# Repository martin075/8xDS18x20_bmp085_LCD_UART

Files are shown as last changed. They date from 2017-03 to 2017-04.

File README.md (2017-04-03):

# 8xDS18x20_bmp085_LCD_UART
it is continue of Tom Blough's termometer. contain Davide Gironi libs BMP085.calculation of pressure must be checked.
project in Atmel Studio 4.18, atmel tool chain 3.4.4, avr-gcc 4.8.1, Fleury's libs uart, twi, i2c updated, Atmega168 8 MHz internal
DS18b20, DS18s20, LCD lib

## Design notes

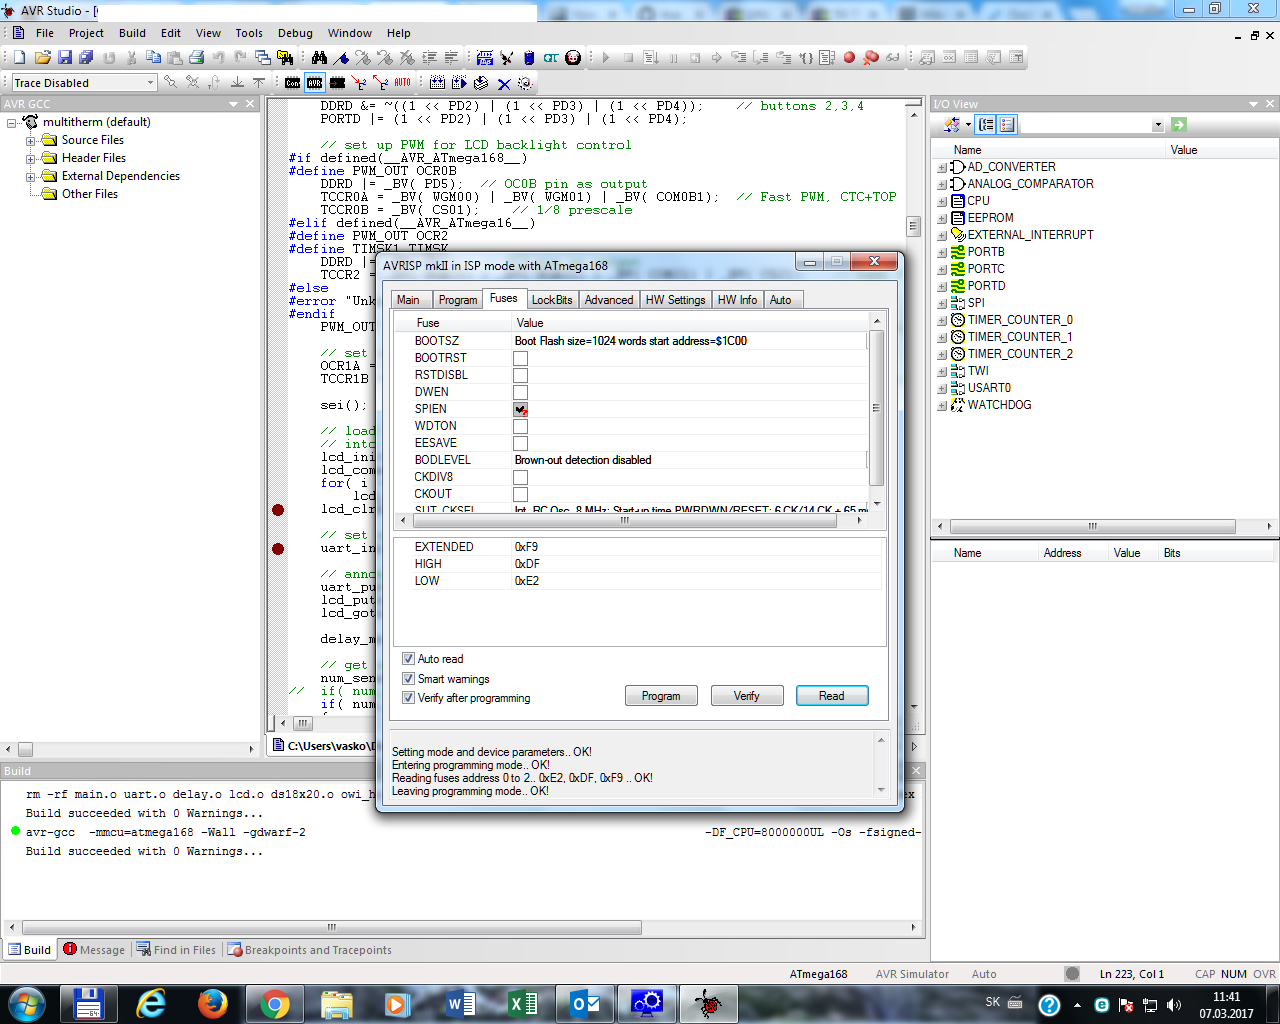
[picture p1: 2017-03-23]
poistky8mhz.png

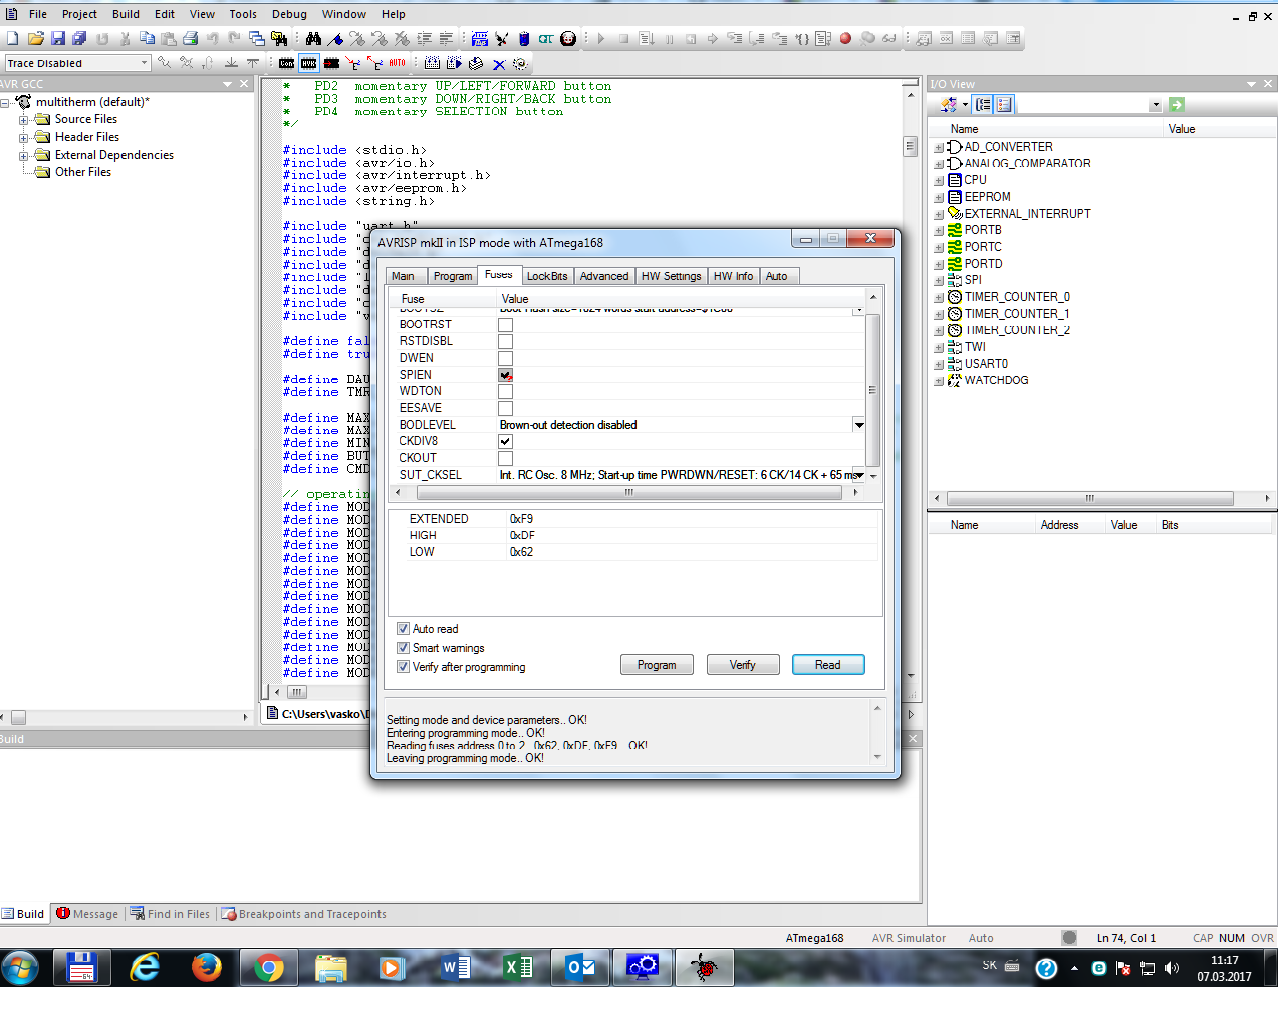
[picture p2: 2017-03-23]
poistky.png

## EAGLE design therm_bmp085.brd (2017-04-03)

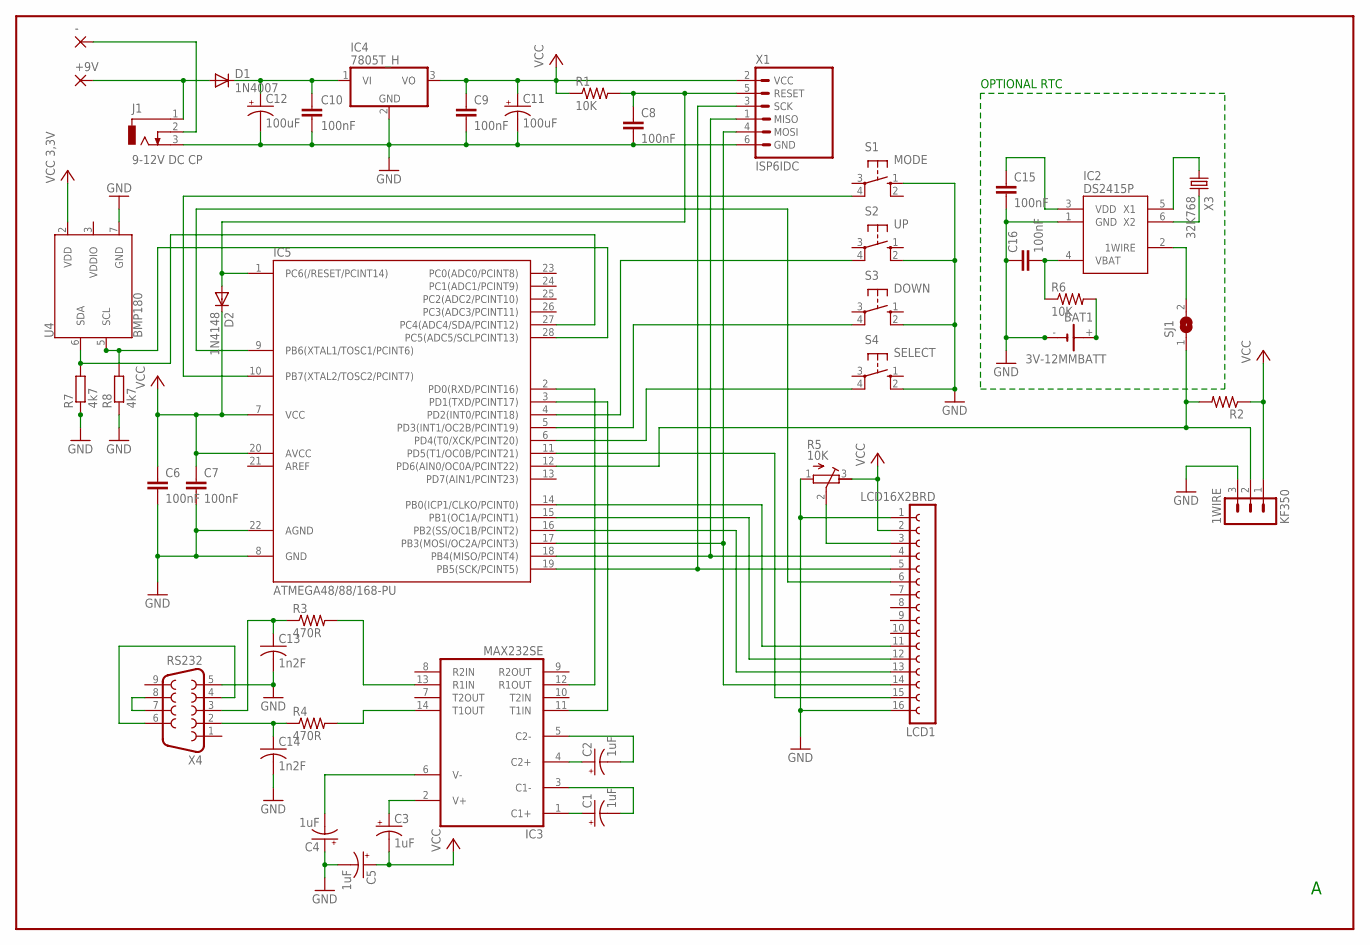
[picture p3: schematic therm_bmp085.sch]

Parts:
1WIRE: KF350
+9V: WIREPAD3,17/1,1; 3,17/1,1
-: WIREPAD3,17/1,1; 3,17/1,1
BAT1: 3V-12MMBATT; KEYELCO3001
C1, C2, C3, C4, C5: 1uF; CT3528
C6, C7, C8, C15, C16: 100nF; C0805
C9, C10: 100nF; C025_050-024X070
C11, C12: 100uF; E2,5-7
C13, C14: 1n2F; C0805
D1: 1N4007; D-10
D2: 1N4148; DO34-7
IC2: DS2415P; TSOC6
IC3: MAX232SE; SO16
IC4: 7805T_H; TO220H
IC5: ATMEGA48/88/168-PU; DIL28-3
J1: 9-12V DC CP; DCJ0202
LCD1: LCD16X2BRD; LCD16X2
R1, R6: 10K; R0805
R2: R-US_0207/10; 0207/10
R3, R4: 470R; R0805
R5: 10K; RTRIM5X
R7, R8: 4k7; 0204V
S1: MODE; B3F-10XX
S2: UP; B3F-10XX
S3: DOWN; B3F-10XX
S4: SELECT; B3F-10XX
SJ1: SJ
U4: BMP180
X1: ISP6IDC; IDC-6
X3: 32K768; TC38H_SMD
X4: RS232; F09D

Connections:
+9V: +9V.1, D1.A, J1.1
GND: 1WIRE.3, BAT1.-, BAT1.-1, BAT1.-2, BAT1.-3, C4.+, C5.-, C6.2, C7.2, C8.2, C9.2, C10.3 (1), C11.-, C12.-, C13.2, C14.2, C15.2, C16.1, IC2.1 (GND), IC3.15 (GND), IC4.2 (GND), IC5.8 (GND), IC5.22 (AGND), J1.3, LCD1.1, LCD1.16, R5.1 (E), R7.1, R8.1, S1.1 (S), S2.2 (S1), S3.2 (S1), S4.2 (S1), U4.7 (GND), X1.6 (GND), X4.5
unnamed: C10.2, C12.+, D1.C, IC4.1 (VI)
unnamed: C3.+, IC3.2 (V+)
unnamed: C4.-, IC3.6 (V-)
unnamed: IC3.12 (R1OUT), IC5.2 (PD0(RXD/PCINT16))
unnamed: IC3.11 (T1IN), IC5.3 (PD1(TXD/PCINT17))
unnamed: C14.1, R4.1, X4.2
unnamed: IC3.14 (T1OUT), R4.2
unnamed: C13.1, R3.1, X4.3
unnamed: IC3.13 (R1IN), R3.2
unnamed: X4.7, X4.8
unnamed: X4.4, X4.6
unnamed: C1.+, IC3.1 (C1+)
unnamed: C1.-, IC3.3 (C1-)
unnamed: C2.-, IC3.5 (C2-)
unnamed: C2.+, IC3.4 (C2+)
unnamed: LCD1.3, R5.2 (S)
unnamed: IC5.10 (PB7(XTAL2/TOSC2/PCINT7)), S1.4 (P1)
unnamed: IC5.9 (PB6(XTAL1/TOSC1/PCINT6)), LCD1.6
unnamed: IC5.19 (PB5(SCK/PCINT5)), LCD1.5, X1.3 (SCK)
unnamed: IC5.18 (PB4(MISO/PCINT4)), LCD1.4, X1.1 (MISO)
unnamed: IC5.17 (PB3(MOSI/OC2A/PCINT3)), LCD1.14, X1.4 (MOSI)
unnamed: IC5.16 (PB2(SS/OC1B/PCINT2)), LCD1.13
unnamed: IC5.15 (PB1(OC1A/PCINT1)), LCD1.12
unnamed: IC5.14 (PB0(ICP1/CLKO/PCINT0)), LCD1.11
unnamed: IC5.11 (PD5(T1/OC0B/PCINT21)), LCD1.15
unnamed: IC5.4 (PD2(INT0/PCINT18)), S2.4 (P1)
unnamed: IC5.5 (PD3(INT1/OC2B/PCINT19)), S3.4 (P1)
unnamed: IC5.6 (PD4(T0/XCK/PCINT20)), S4.4 (P1)
unnamed: 1WIRE.2, IC5.12 (PD6(AIN0/OC0A/PCINT22)), R2.2, SJ1.1
unnamed: IC2.6 (X2), X3.P$2 (2)
unnamed: IC2.5 (X1), X3.P$1 (1)
unnamed: C8.1, D2.A, IC5.1 (PC6(/RESET/PCINT14)), R1.2, X1.5 (RESET)
unnamed: -.1, J1.2
unnamed: IC2.2 (1WIRE), SJ1.2
unnamed: C15.1, IC2.3 (VDD)
unnamed: BAT1.+, BAT1.+1, R6.2
unnamed: IC5.27 (PC4(ADC4/SDA/PCINT12)), IC5.28 (PC5(ADC5/SCLPCINT13)), R7.2, R8.2, U4.5 (SCL), U4.6 (SDA)
VBAT: C16.2, IC2.4 (VBAT), R6.1
VCC: 1WIRE.1, C3.-, C5.+, C6.1, C7.1, C9.3 (1), C11.+, D2.C, IC3.16 (VCC), IC4.3 (VO), IC5.7 (VCC), IC5.20 (AVCC), LCD1.2, R1.1, R2.1, R5.3 (A), U4.2 (VDD), X1.2 (VCC)

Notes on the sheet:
OPTIONAL RTC

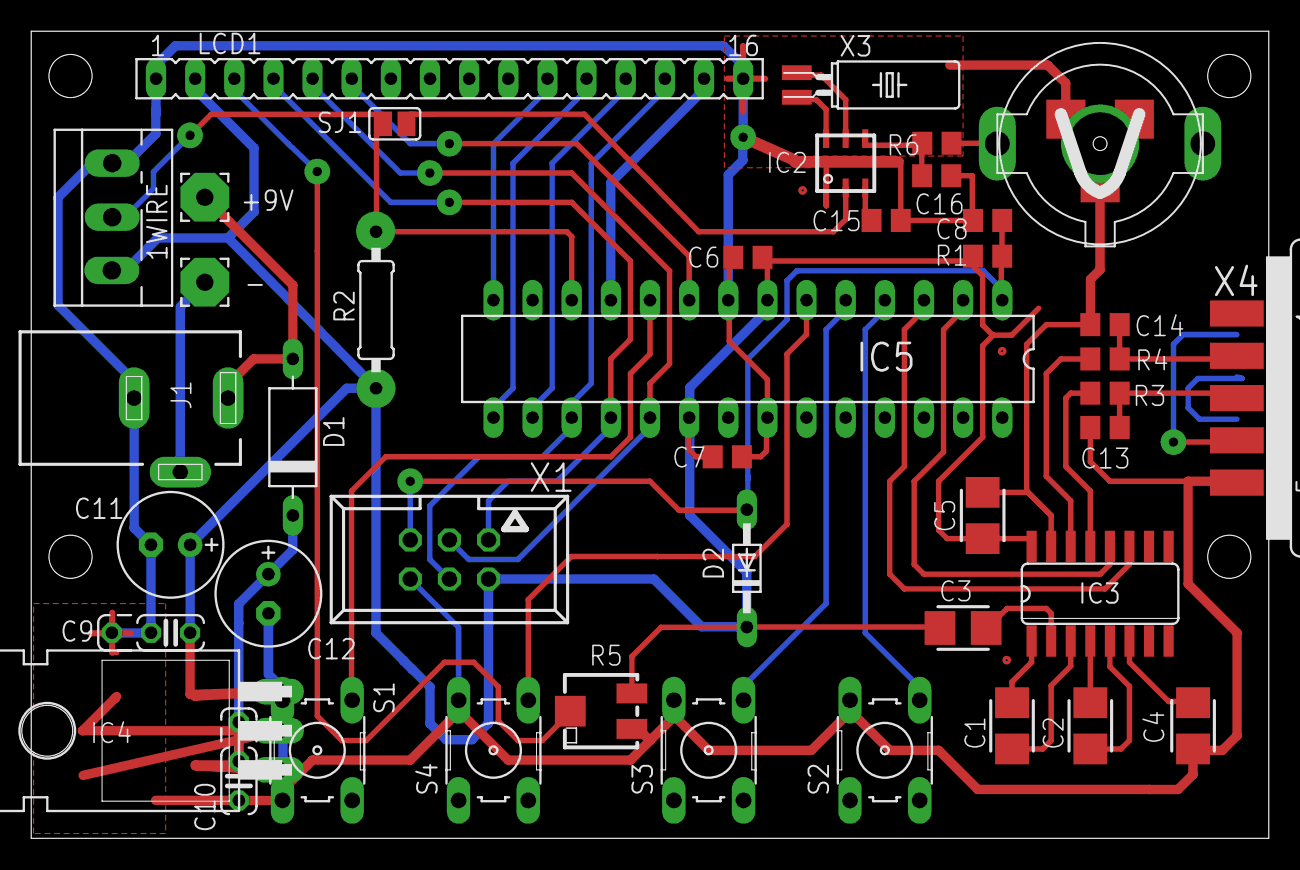
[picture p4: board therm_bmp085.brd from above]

Board: 2 copper layers, 80.3 x 52.4 mm, 42 parts (0 on the bottom side), 40 nets.

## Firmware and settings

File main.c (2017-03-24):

/*
* Program: Multitherm - A multiple DS18x20 thermometer control and logging device
* File Name: crc.c
* Purpose: Implements an AVR based temperature logging device
*
*	Reads multiple Dallas Semiconductor DS18x20 1-Wire
*	thermometers and sends the data via serial port for
*	logging by an external program.  Displays the
*	temperature data via an attached LCD as well.  Serial records
*	are timestamped using an elapsed time counter value, or a DS2415
*	1-Wire Real Time Clock timestamp if the device is present
*	on the 1-Wire bus.
*
*	Uses Peter Fleury's uart-library and lcd-library
*	which are very portable between AVRs.  Martin Thomas
*	added some functions in the uart-lib.
*
*	Contains code from DS18x20 Demo-Programm by
*	Martin Thomas <eversmith@heizung-thomas.de>
*	http://www.siwawi.arubi.uni-kl.de/avr-projects
*
*	Created using Atmel STK500, Atmega16L @ 8MHz
*	internal oscillator clock.
*
*    Programmer: Tom Blough
*   Host System: ATMega16L tested with both internal RC osc at 8MHz
*                and external 8MHz crystal
*  Date Created: 2007/09/20
*      Revision: 2007/12/18 - loop page display and sensor display
*                             fix bug in initial sensor order - was not writing to nvRam
*                2008/08/16 - added sanity checks when loading data from SRAM
*                2017/03     added saving adresses into EEPROM 
*				 2017/03 - upgraded libs UART.c, UART.h for avr-gcc 4.8.1 (Fleury 2015)
*				 2017/03 - reading data from BMP085 - temp, altitude, pressure
*                do not mix 18b20 family and 1820/18s20
*
* Host Configuration ATMega16:
*	PB0  LCD_DATA_4
*	PB1  LCD_DATA_5
*	PB2  LCD_DATA_6
*	PB3  LCD_DATA_7
*	PB4  LCD_DATA_RS
*	PB5  LCD_DATA_R/W
*	PB6  LCD_DATA_E
*
*	PD0  RxD, 19200,8,n,1
*	PD1  TxD
*	PD6  1-Wire Data, external 15K pullup
*	PD7  PWM LCD Backlight (OC2)
*
*	PB7  momentary MODE button
*	PD2  momentary UP/LEFT/FORWARD button
*	PD3  momentary DOWN/RIGHT/BACK button
*	PD4  momentary SELECTION button
*
* Host Configuration ATMega168, 8MHz:
*  note- on STK500, PB6 and PB7 are not routed to PortB header
*  instead they are routed to PortE XT1/XT2
*	PB0  LCD_DATA_4
*	PB1  LCD_DATA_5
*	PB2  LCD_DATA_6
*	PB3  LCD_DATA_7
*	PB4  LCD_DATA_RS
*	PB5  LCD_DATA_R/W
*	PB6  LCD_DATA_E
*
*	PD0  RxD, 19200,8,n,1
*	PD1  TxD
*	PD6  1-Wire Data, external 15K pullup
*	PD5  PWM LCD Backlight (OC2)
*
*	PB7  momentary MODE button
*	PD2  momentary UP/LEFT/FORWARD button
*	PD3  momentary DOWN/RIGHT/BACK button
*	PD4  momentary SELECTION button
*/

#include <stdio.h>
#include <avr/io.h>
#include <avr/interrupt.h>
#include <avr/eeprom.h>
#include <string.h>

#include "uart.h"
#include "owi_highlevel.h"
#include "ds18x20.h"
#include "ds2415.h"
#include "lcd.h"
#include "delay.h"
#include "crc.h"
#include "version.h"

// libs for BMP085
#include "bmp085.h"
#include <math.h>

#define false 0
#define true !false

#define BAUD 19200
#define TMR_TICK 200L	// 200Hz = 5ms

#define MAX_SENSORS 8			// we can handle only sensor ID's from 0-9 (display constraint on order page)
#define MAX_INTERVAL 9999	// maximum number of seconds between log entries
#define MIN_INTERVAL 5		// minimum number of seconds between log entries
#define DEF_INTERVAL 15		//default interval of log entries, sec
#define HYSTER 10					// hysterezia 
#define DEF_BACKLIGHT 240	//default value of backlight
#define BUTTON_HELD 3			// number of CMD_DELAY cycles until button considered held
#define CMD_DELAY 200			// ms to wait between command executions

// operating states
#define MODE_LOGGING 0	// actively reading and logging temperatures
#define MODE_START 1	// displaying start logging message
#define MODE_ORDER 2	// displaying change view order
#define MODE_INTERVAL 3	// displaying interval change
#define MODE_SENSOR 4	// displaying extended sensor info
#define MODE_BACKLIGHT 5	// displaying PWM LCD backlight change
#define MODE_SHOW_DATE 6	// display RTC date
#define MODE_SET_YEAR 7	// change year value
#define MODE_SET_MONTH 8	// change month value
#define MODE_SET_DAY 9	// change day value
#define MODE_SET_HOUR 10	// change hour value
#define MODE_SET_MIN 11	// change minutes value
#define MODE_SET_SEC 12	// change seconds value
#define MODE_WRITE_DATE 13	// commit changes to RTC


// EEPROM storage of persistant variables
uint16_t EEMEM nvLog_interval = 10;	// default program load with 10 second timer
uint8_t EEMEM nvBacklight = DEF_BACKLIGHT;	// default program load to half-bright
uint8_t EEMEM nvNum_sensors;	// previous number of sensors
uint8_t EEMEM nv1Wire_order[MAX_SENSORS];	// previous display order
//uint8_t EEMEM nvgSensorIDsEE[MAX_SENSORS][OWI_ROMCODE_SIZE];
uint8_t EEMEM nvgSensorIDs1[OWI_ROMCODE_SIZE]; //out temp
uint8_t EEMEM nvgSensorIDs2[OWI_ROMCODE_SIZE]; //pumpwell temp
uint8_t EEMEM nvgSensorIDs3[OWI_ROMCODE_SIZE]; //cellar temp
uint8_t EEMEM nvgSensorIDs4[OWI_ROMCODE_SIZE]; //boiler temp
uint8_t EEMEM nvgSensorIDs5[OWI_ROMCODE_SIZE];
uint8_t EEMEM nvgSensorIDs6[OWI_ROMCODE_SIZE];
uint8_t EEMEM nvgSensorIDs7[OWI_ROMCODE_SIZE];
uint8_t EEMEM nvgSensorIDs8[OWI_ROMCODE_SIZE];

// buttons - checks if pressed and returns 0x01 or 0 if not pressed
#define BTN_MODE ((~PINB & (1 << PB7)) >> PB7)
#define BTN_UP ((~PIND & (1 << PD2)) >> PD2)
#define BTN_DOWN ((~PIND & (1 << PD3)) >> PD3)	
#define BTN_SEL ((~PIND & (1 << PD4)) >> PD4)	

// custom characters for LCD display
static const PROGMEM unsigned char lcdChars[] =
{
	0x04, 0x04, 0x04, 0x04, 0x15, 0x1F, 0x0E, 0x04,	// down arrow - chr(0)
	0x04, 0x0E, 0x1F, 0x15, 0x04, 0x04, 0x04, 0x04	// up arrow - chr(1)
};

// Module global variables
uint8_t gRTC_ID[OWI_ROMCODE_SIZE];	// id for DS2415 RTC if available
uint8_t gSensorIDs[MAX_SENSORS][OWI_ROMCODE_SIZE];	// active 1-wire thermometer sensors
uint8_t gRTC[OWI_ROMCODE_SIZE];	// active 1-wire RTC
uint8_t g1Wire_order[MAX_SENSORS];	// contains output ordering of 1-Wire thermometer devices
int gReadings[MAX_SENSORS];	// contains decicelsius readings for all thermometer sensors
int gReadings_old[MAX_SENSORS];	//previous reading temp
char gBuffer[21];	// used for itoa conversions and sprintf buffer
int gLog_interval;	// time period between log entries
uint8_t gBacklight;	// holds PWM value for LCD backlight brightness

//for bmp085
long l;
double d;
char printbuff[10];


//int *pom2; // pomocna premenna predchadzajuci odpocet teploty

// folowing are static because they are accessed within timer ISR
static uint8_t gRTC_status = 0;	// RTC status byte
static uint32_t gRTC_clk = 0;	// RTC epoch clock
static volatile uint16_t gElapsed;	// gElapsed counter for temperature reading period
//static volatile uint16_t min_counter; // counter for minutes

// forward declarations
uint8_t onewire_search( void);
void display_temperatures( uint8_t num_sensors, uint8_t page);
void log_temperatures( uint8_t num_sensors);
void read_temperatures( uint8_t num_sensors);
void show_id_uart( uint8_t *id);
void show_exinfo_lcd( uint8_t index);



/****************************************************************************************
 *                                                                                      *
 *           Main Entry Point                                                           *
 *                                                                                      *
 ***************************************************************************************/
int main( void)
{
	uint8_t i, num_sensors, device, page, mode, pos, tmp, up_held, dn_held;
	uint16_t bitmap;
//	DS2415_date_t dt;	// date structure for RTC

	// set unused I/O to input and enable pull-ups;
	DDRC = 0;	// all of port C is unused
	PORTC = 0x0f;
#if defined(__AVR_ATmega168__)
	DDRD &= ~(1 << PD7);
	PORTD |= (1 << PD7);
#elif defined(__AVR_ATmega16__)
	DDRD &= ~(1 << PD5);
	PORTD |= (1 << PD5);
#else
#error "Unknown target device"
#endif
	
	// enable our push buttons
	DDRB &= ~(1 << PB7);	// set for input - button 1
	PORTB |= (1 << PB7);	// enable pull-up
	DDRD &= ~((1 << PD2) | (1 << PD3) | (1 << PD4));	// buttons 2,3,4
	PORTD |= (1 << PD2) | (1 << PD3) | (1 << PD4);

	// set up PWM for LCD backlight control
#if defined(__AVR_ATmega168__)
#define PWM_OUT OCR0B
	DDRD |= _BV( PD5);	// OC0B pin as output
	TCCR0A = _BV( WGM00) | _BV( WGM01) | _BV( COM0B1);	// Fast PWM, CTC+TOP
	TCCR0B = _BV( CS01);	// 1/8 prescale
#elif defined(__AVR_ATmega16__)
#define PWM_OUT OCR2
#define TIMSK1 TIMSK
	DDRD |= _BV( PD7);	// OC2 pin as output
	TCCR2 = _BV( WGM20) | _BV( WGM21) | _BV( COM21) | _BV( CS21);	// fast PWM, CTC+TOP, 1/8 prescale
#else
#error "Unknown target device"
#endif
	PWM_OUT = gBacklight = eeprom_read_byte( &nvBacklight);	// grab our persistant data

	// set up the elapsed timer
	OCR1A = F_CPU / TMR_TICK;	// timer = 5 msec
	TCCR1B = _BV( WGM12) + _BV( CS10);	// clear timer on compare match, no prescaler

	sei();	// enable global interrupts
	
	// load userdefined characters from program memory
	// into LCD controller CG RAM
	lcd_init( LCD_DISP_ON);
	lcd_command( _BV( LCD_CGRAM));	/* set CG RAM start address 0 */
	for( i = 0; i < (sizeof lcdChars / sizeof lcdChars[0]); i++)
		lcd_data( pgm_read_byte_near( &lcdChars[i]));
	lcd_clrscr();

	// set up the comm port
	uart_init( UART_BAUD_SELECT( BAUD, F_CPU));
	
	// set up bmp085board
	bmp085_init();

	// announce our birth
	uart_puts_P( "DS1820,BMP180 Logger v" MAJOR_VER "." MINOR_VER "\r");
	lcd_gotoxy( 0, 0);
	lcd_puts_P( "DS18x20 Logger v" MAJOR_VER "." MINOR_VER "\r");
	//lcd_gotoxy( 0, 1);
	lcd_puts_P( "   BMP180 Logger");
	
	delay_ms( 1000);	// pause lcd display for a moment

	// get attached 1-wire sensor info
	num_sensors = onewire_search();
	if( num_sensors == 0 && ! gRTC_status) // bolo povodne
//	if( num_sensors == 0) 
	{
		lcd_gotoxy( 0, 2);
		lcd_puts_P( "No DS Sensors Found");
		uart_puts_P( "No Sensors Found");
	} 
	else
	{
		// display the count of sensors found on 1-Wire bus
		itoa( (int)num_sensors, gBuffer, 10);
		lcd_gotoxy( 0, 2);
		lcd_puts( gBuffer);
		lcd_puts_P( " Sensor(s)");
		uart_puts( gBuffer);
		uart_puts_P( " DS18X20 Sensor(s) available\r");
	}
	delay_ms( 2000);	// pause lcd display for a moment
	
	
	// initialize 1-wire output order from EEPROM.  make sure the order we read in
	// accounts for every sensor number by flipping the corresponding bit for each sensor
	// in the bitmap
	bitmap = 0;
	for( i = 0; i < num_sensors; i++)
		bitmap |= _BV( i);
		if( eeprom_read_byte( &nvNum_sensors) == num_sensors)
		{
		// assume if we have same number of sensors, we want to use the prev. order
		 eeprom_read_block( g1Wire_order, nv1Wire_order, MAX_SENSORS);

		// in the order we just loaded, check to see if all sensor
		// numbers were accounted for, by turning off bits in the bitmap
		 for( i = 0; i < num_sensors; i++)
			 bitmap &= ~_BV( g1Wire_order[i]);
		}

	if( bitmap != 0)	// were any sensors unaccounted for?
	{
		// yes, so load the default order
		eeprom_write_byte( &nvNum_sensors, num_sensors);
		for( i = 0; i < num_sensors; i++)
			g1Wire_order[i] = i;
		eeprom_write_block( g1Wire_order, nv1Wire_order, MAX_SENSORS);
	}

	// load and sanitize the reading interval from EEPROM
	gLog_interval = eeprom_read_word( &nvLog_interval);
	if( gLog_interval > MAX_INTERVAL || gLog_interval < MIN_INTERVAL)
	{
		gLog_interval = DEF_INTERVAL;  // bola min hodnota
		eeprom_write_word( &nvLog_interval, gLog_interval);	// save the persistant value
	}
		
	// don't worry about backlight since it's only 1 byte it WILL be between 0 and 255
		
		
	//					 setup for main loop*********************************************
	page = 0;
	lcd_clrscr();
	mode = MODE_START;	// first choice 
	TIMSK1 = _BV( OCIE1A);	// enable Output Compare 1 overflow interrupt to start elapsed timer

	// main loop - state machine
	while( true)
	{
		switch( mode)
		{
		case MODE_LOGGING:	// actively reading and logging temperatures***********
			{
				while( true)	// display loop
				{
					if( BTN_DOWN)	//vyhodnotenie stavu PINu - show previous 2 readings on LCD
					{
						// give a small delay to see if this is a simultaneous press
						delay_ms( CMD_DELAY);
						if( BTN_UP) break;	// exit display loop
						// cycle if needed
						if( page >= 4) page -= 2;          // if( page >= 2) page -= 2;
						else page = ((num_sensors - 1) >> 1) << 1; // bitovy posun - nasobenie
						lcd_clrscr();
						display_temperatures( num_sensors, page);
						while( BTN_DOWN);	// wait until switch released
					}
					else if( BTN_UP)	// show next 2-4 readings on LCD
					{
						// give a small delay to see if this is a simultaneous press
						delay_ms( CMD_DELAY);
						if( BTN_DOWN) break;	// exit display loop
						// cycle if needed
						if( page + 4 < num_sensors) page += 2; //boli 2 a 2
						else page = 0;
						lcd_clrscr();
						display_temperatures( num_sensors, page);
						while( BTN_UP);	// wait until switch released
					}
					else
					{
						// time for a new reading?
						if( gElapsed >= gLog_interval)
						{
							read_temperatures( num_sensors);
							log_temperatures( num_sensors);
							lcd_clrscr();
							display_temperatures( num_sensors, page);
							gElapsed = 0;	// restart the interval timer
						}
						// update the countdown.
						// else use the pseudo elapsed time counter
						lcd_gotoxy( 15, 0);
						sprintf( gBuffer, "%4is", gLog_interval - gElapsed);
						lcd_puts( gBuffer);
					}
				}
				mode = MODE_START;
				lcd_clrscr();	// provide feedback on button push
				while( BTN_UP || BTN_DOWN);	// wait until switches released
				break;	// next case
			}
		case MODE_START:	// displaying start logging message**********************
			{
				if( ! num_sensors > 0)
					{
					// no sensors found so skip all sensor related modes
					mode = MODE_BACKLIGHT;
					break;
					}
				lcd_clrscr();
				lcd_puts_P( "Start Logging?\n");
				lcd_putc( 0);	// down arrow
				lcd_puts_P( " or ");
				lcd_putc( 1);	// up arrow
				lcd_puts_P( " to start\n\n");
				lcd_puts_P( "press MODE to other");
				while( ! (BTN_MODE || BTN_UP || BTN_DOWN || BTN_SEL));	// wait for a button press
				// if mode button pressed, change to next state
				if( BTN_MODE)
					{
					lcd_clrscr();	// provide feedback on button push
					mode = MODE_ORDER;
					while( BTN_MODE);	// wait for release
					}
				else	// any other button, start logging
					{
						lcd_clrscr();	// provide feedback on button push
						mode = MODE_LOGGING;
						while( BTN_UP || BTN_DOWN || BTN_SEL);	// wait for release
								// send the extended sensor info out the comm port
						uart_puts_P( "\r\r");
						for( i = 0; i < num_sensors; i++)
							{
							device = g1Wire_order[i];
							uart_puts_P( "Sensor Display");
							uart_puti( (int)i);
							uart_puts_P( " / Bus");
							uart_puti( g1Wire_order[i]);
							uart_puts_P( " is a ");
							if( OWI_FAMILY( gSensorIDs[device][0]) == DS18S20_FAMILY_CODE)
									uart_puts_P( "DS18S20/DS1820");
							else uart_puts_P( "DS18B20");
							uart_puts_P( " = ");
							show_id_uart( &gSensorIDs[device][0]);
							uart_puts_P("\r");
							}
						uart_puts_P( "\r\r");
							// if no RTC clock present, reset the elapsed timer
						if( ! gRTC_status)
									gRTC_clk = 0;
						lcd_clrscr();
						read_temperatures( num_sensors);
						log_temperatures( num_sensors);
						display_temperatures( num_sensors, page);
						gElapsed = 0;	// restart the interval timer
					}
				break;	// next case MODE LOGGING
			}
		case MODE_ORDER:	// displaying change view order**************************
			{
				// this alters the Dallas 1Wire search order which appears random,
				// but is deterministic, to a more meaningful user selected order
				pos = 0;	// start on the left
				lcd_gotoxy( 1, 3);
				lcd_puts_P( "write to EEPROM");
				lcd_gotoxy( 0, 0);
				lcd_puts_P( "1Wire display order");
				lcd_gotoxy( 0, 1);
				for( i = 0; i < num_sensors; i++)	// display the 1-wire order
					lcd_putc( g1Wire_order[i] + '0');
				lcd_gotoxy( pos, 1);
				lcd_command( LCD_DISP_ON_BLINK);	// turn on flashing block cursor
				
				while( ! BTN_MODE)
				{
					if( BTN_SEL)	// next ID
					{
						// move the cursor position right one - recycle if at end
						pos++;
						if( pos > num_sensors - 1) pos = 0;
						lcd_gotoxy( pos, 1);

						while( BTN_SEL);	// wait for release
					}
					else if( BTN_UP)	// move selection to the left
					{
						if( pos > 0)
						{
							// swap marker positions
							tmp = g1Wire_order[pos];
							g1Wire_order[pos] = g1Wire_order[pos - 1];
							g1Wire_order[pos - 1] = tmp;
							pos--;
							// display the markers in the new order
							lcd_gotoxy( 0, 1);
							for( i = 0; i < num_sensors; i++)
								lcd_putc( g1Wire_order[i] + '0');
							lcd_gotoxy( pos, 1);
						}
						while( BTN_UP);	// wait until switch released
					}
					else if( BTN_DOWN)	// move selection to the right
					{
						if( pos < num_sensors - 1)
						{
							// swap marker positions
							tmp = g1Wire_order[pos];
							g1Wire_order[pos] = g1Wire_order[pos + 1];
							g1Wire_order[pos + 1] = tmp;
							pos++;
							// display the markers in the new order
							lcd_gotoxy( 0, 1);
							for( i = 0; i < num_sensors; i++)
								lcd_putc( g1Wire_order[i] + '0');
							lcd_gotoxy( pos, 1);
						}
						while( BTN_DOWN);	// wait until switch released
					}
				}
				eeprom_write_block( g1Wire_order, nv1Wire_order, MAX_SENSORS);
				
				if(num_sensors==1)
						{ nvgSensorIDs1[1] = gSensorIDs[1][0];
							eeprom_write_block( gSensorIDs, nvgSensorIDs1, 8);
						}
				if(num_sensors==2)
						{nvgSensorIDs1[1] = gSensorIDs[1][0];
						eeprom_write_block( gSensorIDs, nvgSensorIDs1, 8);
						nvgSensorIDs2[1] = gSensorIDs[2][0];
						eeprom_write_block( gSensorIDs, nvgSensorIDs2, 8);
						}
				if(num_sensors==3)
						{nvgSensorIDs1[1] = gSensorIDs[1][0];
						eeprom_write_block( gSensorIDs, nvgSensorIDs1, 8);
						nvgSensorIDs2[1] = gSensorIDs[2][0];
						eeprom_write_block( gSensorIDs, nvgSensorIDs2, 8);
						nvgSensorIDs3[1] = gSensorIDs[3][0];
						eeprom_write_block( gSensorIDs, nvgSensorIDs3, 8);
						}
				if(num_sensors==4)
						{nvgSensorIDs1[1] = gSensorIDs[1][0];
						eeprom_write_block( gSensorIDs, nvgSensorIDs1, 8);
						nvgSensorIDs2[1] = gSensorIDs[2][0];
						eeprom_write_block( gSensorIDs, nvgSensorIDs2, 8);
						nvgSensorIDs3[1] = gSensorIDs[3][0];
						eeprom_write_block( gSensorIDs, nvgSensorIDs3, 8);
						nvgSensorIDs4[1] = gSensorIDs[4][0];
						eeprom_write_block( gSensorIDs, nvgSensorIDs4, 8);
						}
			/*	if(num_sensors==5)
						{nvgSensorIDs1[1] = gSensorIDs[1][0];
						eeprom_write_block( gSensorIDs, nvgSensorIDs1, 8);
						nvgSensorIDs2[1] = gSensorIDs[2][0];
						eeprom_write_block( gSensorIDs, nvgSensorIDs2, 8);
						nvgSensorIDs3[1] = gSensorIDs[3][0];
						eeprom_write_block( gSensorIDs, nvgSensorIDs3, 8);
						nvgSensorIDs4[1] = gSensorIDs[4][0];
						eeprom_write_block( gSensorIDs, nvgSensorIDs4, 8);
						nvgSensorIDs5[1] = gSensorIDs[5][0];
						eeprom_write_block( gSensorIDs, nvgSensorIDs5, 8);
						}
				if(num_sensors==6)
						{nvgSensorIDs1[1] = gSensorIDs[1][0];
						eeprom_write_block( gSensorIDs, nvgSensorIDs1, 8);
						nvgSensorIDs2[1] = gSensorIDs[2][0];
						eeprom_write_block( gSensorIDs, nvgSensorIDs2, 8);
						nvgSensorIDs3[1] = gSensorIDs[3][0];
						eeprom_write_block( gSensorIDs, nvgSensorIDs3, 8);
						nvgSensorIDs4[1] = gSensorIDs[4][0];
						eeprom_write_block( gSensorIDs, nvgSensorIDs4, 8);
						nvgSensorIDs5[1] = gSensorIDs[5][0];
						eeprom_write_block( gSensorIDs, nvgSensorIDs5, 8);
						nvgSensorIDs6[1] = gSensorIDs[6][0];
						eeprom_write_block( gSensorIDs, nvgSensorIDs6, 8);
						}
				if(num_sensors==7)
						{nvgSensorIDs1[1] = gSensorIDs[1][0];
						eeprom_write_block( gSensorIDs, nvgSensorIDs1, 8);
						nvgSensorIDs2[1] = gSensorIDs[2][0];
						eeprom_write_block( gSensorIDs, nvgSensorIDs2, 8);
						nvgSensorIDs3[1] = gSensorIDs[3][0];
						eeprom_write_block( gSensorIDs, nvgSensorIDs3, 8);
						nvgSensorIDs4[1] = gSensorIDs[4][0];
						eeprom_write_block( gSensorIDs, nvgSensorIDs4, 8);
						nvgSensorIDs5[1] = gSensorIDs[5][0];
						eeprom_write_block( gSensorIDs, nvgSensorIDs5, 8);
						nvgSensorIDs6[1] = gSensorIDs[6][0];
						eeprom_write_block( gSensorIDs, nvgSensorIDs6, 8);
						nvgSensorIDs7[1] = gSensorIDs[7][0];
						eeprom_write_block( gSensorIDs, nvgSensorIDs7, 8);
						}
				if(num_sensors>=8)
						{nvgSensorIDs1[1] = gSensorIDs[1][0];
						eeprom_write_block( gSensorIDs, nvgSensorIDs1, 8);
						nvgSensorIDs2[1] = gSensorIDs[2][0];
						eeprom_write_block( gSensorIDs, nvgSensorIDs2, 8);
						nvgSensorIDs3[1] = gSensorIDs[3][0];
						eeprom_write_block( gSensorIDs, nvgSensorIDs3, 8);
						nvgSensorIDs4[1] = gSensorIDs[4][0];
						eeprom_write_block( gSensorIDs, nvgSensorIDs4, 8);
						nvgSensorIDs5[1] = gSensorIDs[5][0];
						eeprom_write_block( gSensorIDs, nvgSensorIDs5, 8);
						nvgSensorIDs6[1] = gSensorIDs[6][0];
						eeprom_write_block( gSensorIDs, nvgSensorIDs6, 8);
						nvgSensorIDs7[1] = gSensorIDs[7][0];
						eeprom_write_block( gSensorIDs, nvgSensorIDs7, 8);
						nvgSensorIDs8[1] = gSensorIDs[8][0];
						eeprom_write_block( gSensorIDs, nvgSensorIDs8, 8);
						}
			*/	
				lcd_command( LCD_DISP_ON);	// turn off flashing cursor
				lcd_clrscr();	// acknowledge button press
				mode = MODE_INTERVAL;
				while( BTN_MODE);	// wait until switch released
				break;	// next case
			}
		case MODE_INTERVAL:	// displaying logging interval change******************
			{
				lcd_clrscr();
				lcd_puts_P( "Logging interval\n");
				sprintf( gBuffer, "%4i", gLog_interval);
				lcd_puts( gBuffer);
				//lcd_puts_P( "Logging interval\n");
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

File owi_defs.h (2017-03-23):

#ifndef _OWI_DEFS_
#define _OWI_DEFS_

// 1-Wire Hardware connection - change depending on setup
#define OWI_PIN PD6
#define OWI_IN PIND
#define OWI_OUT PORTD
#define OWI_DDR DDRD

// Bit timing delays from Maxim-IC Application Note 126
#define OWI_DELAY_A 6
#define OWI_DELAY_B 64
#define OWI_DELAY_C 60
#define OWI_DELAY_D 10
#define OWI_DELAY_E 9
#define OWI_DELAY_F 55
#define OWI_DELAY_G 0
#define OWI_DELAY_H 480
#define OWI_DELAY_I 70
#define OWI_DELAY_J 410

#define OWI_READ_ROM 0x33
#define OWI_MATCH_ROM 0x55
#define OWI_SKIP_ROM 0xCC
#define	OWI_SEARCH_ROM 0xF0
#define	OWI_ALARM_SEARCH 0xEC

// rom-code size including CRC
#define OWI_ROMCODE_SIZE 8

// error codes
#define OWI_BUS_OK 0x00
#define OWI_ROM_CRC_OK 0x00 
#define OWI_BUS_ERROR 0xFF
#define OWI_PRESENCE_ERROR	0xFE
#define	OWI_DATA_ERR 0xFD
#define OWI_ROM_CRC_ERROR 0xFC


#endif // _OWI_DEFS_

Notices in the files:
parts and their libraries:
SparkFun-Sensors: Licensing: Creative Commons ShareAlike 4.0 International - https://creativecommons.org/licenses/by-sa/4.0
